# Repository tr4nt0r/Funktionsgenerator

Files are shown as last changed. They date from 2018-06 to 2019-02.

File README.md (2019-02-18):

# Funktionsgenerator
Funktionsgenerator basierend auf dem DDS AD9833 mit einem Atmega328PB (Arduino) als Mikrocontroller und einem 1,8" TFT Display

Function generator with AD9833 DDS, Atmega328PB Microcontroller and a 1.8" TFT Display

## Bill of Materials
### AD9833 & µController Board

| Qty | Value | Device | Package | Description | Vendor | Price |
| ---: | :--- | :--- | :--- | :--- | :--- | ---: |
| 1 | | KMR-1.8 SPI ST7735R | | 1.8" TFT Display |  [eBay](https://www.ebay.de/sch/i.html?_from=R40&_trksid=m570.l1313&_nkw=1%2C8%22+tft+spi+st7735r&_sacat=0) | 2,88€ |
| 1 | | SPDT | | Toggle switch for Front Panel Mount | [eBay](https://www.ebay.de/sch/i.html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) | 3,00€ |
| 1 |  | KY-040 | | Rotary Encoder mit Taster (Ausführung mit Gewinde am Schaft und Befestigungsmutter) |  [eBay](https://www.ebay.de/itm/Drehregler-Drehgeber-Rotary-Encoder-Arduino-KY-040-Potentiometer-Poti-Raspberry/252713917550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)| 4€ |
| 1 | 1,3k | Resistor | 0603 | | | 0,01€
| 1 | 620 | Resistor | 0603 |||0,01€|
| 8 | 100n | Capacitor | 0603 | | | 0,01€
| 4 | 10k | Resistor | 0603 ||| 0,01€|
| 1 | 10n | Capacitor| 0603||| 0,01€ |
| 1 |16Mhz | Crystal | SMD HC-49/U-S | 16.000MHz QCS HC49/U-S SMD Crystal 16MHz, 20ppm, 2-Pin HC-49/U-S SMD | [RS Components](https://de.rs-online.com/web/p/quarzmodule/8149535/)|0,25€|
| 1 | 1k |Potentiometer|| for Front Panel Mount | [RS Components](https://de.rs-online.com/web/p/products/8427030/)| 5,88€|
| 1 | 25k | Potentiometer || for Front Panel Mount| [RS Components](https://de.rs-online.com/web/p/products/8427059/)| 5,85€|
| 2 | 22p | Capacitor | 0603 | || 0,01€|
| 1 | 24.0Mhz | CFPS-72 | 7 x 5 mm SMD | | [RS Components](https://de.rs-online.com/web/p/products/8141581/)|1,25€|
|1 | 330n | Capacitor | 0603 | || 0,01€|
| 1 | | AD9833BRMZ | MSOP-10 | Programmable Waveform Generator | [Mouser](https://www.mouser.de/ProductDetail/Analog-Devices/AD9833BRMZ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) or [eBay](https://www.ebay.de/sch/i.html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)|7,79€|
| 1 | | ATMEGA328PB-AU | TQFP-32 | ATMEL - ATMEGA328PB-AU - MCU, 8BIT, ATMEGA, 20MHZ | [RS Components](https://de.rs-online.com/web/p/products/1468920/)|1,61€|
| 1 | 50Ohm | BNC Connector | | for Front Panel Mount | [RS Components](https://de.rs-online.com/web/p/products/5121174/)|2,15€|
| 1 | 10u | EEEFK1C100AR | Panasonic B | Panasonic 10uF 16 Vdc SMD Electrolytic Capacitor | [RS Components](https://de.rs-online.com/web/p/products/0565572/)|0,45€|
| 1 | 47u | Capacitor | Case D| Polarized Tantal Capacitor 10Vdc | [RS Components](https://de.rs-online.com/web/p/products/6993175/) | 0,36€|
| 2 | | LM318D | SO-08 | OpAmp | [RS Components](https://de.rs-online.com/web/p/products/6610524/) | 1,64€|
| 1 | | TLE4270-2D | TO-252 | LDO Voltage Regulator, 850mA, 5 V | [RS Components](https://de.rs-online.com/web/p/ldo-spannungsregler/1109087/) | 2,44€|

### Power Supply Board

| Qty | Value | Device | Package | Description | Vendor | Price |
| ---: | :--- | :--- | :--- | :--- | :--- | ---: |
|2 | 100n| Capacitor | 0603 | ||| 0,01€|
|1 | 2x12V 6VA | Transformer | | PCB Mount | [RS Components](https://de.rs-online.com/web/p/products/1213841/) | 5,75€|
|2 | 100u | EEEFT1C101AR | Panasonic C | Panasonic 100uF 16 Vdc SMD Electrolytic Capacitor | [RS Components](https://de.rs-online.com/web/p/aluminium-elektrolytkondensatoren/7472499/) | 0,35€|
|2 | 1000u/35V | Electrolyic Capacitor |E5-13| | [RS Components](https://de.rs-online.com/web/p/aluminium-elektrolytkondensatoren/7111337/) | 0,46€|
|1 | | MB6S| SOIC-4 | Bridge Rectifier | [RS Components](https://de.rs-online.com/web/p/products/6290322/)|0,35€|
| 1 |+12V| MC7812|DPAK| Positive Voltage Regulator| [RS Components](https://de.rs-online.com/web/p/products/6889250/)|0,70€|
|1|-12V| MC79M12|DPAK | Netgative Voltage Regulator|[RS Components](https://de.rs-online.com/web/p/products/6889326/)|0,65€|

#### Pin Connectors
You will need several pin headers and connectors , 2x2 Pin, 2x3 Pin, 1x 5 Pin. You could use any connector with a pitch of 0,1"/2,54mm either regular pinheaders or [Molex KK 254 Connectors](https://de.rs-online.com/web/c/steckverbinder/leiterplattensteckverbinder/leiterplatten-header/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,4293240458,4294519411,4294519436,4294516238,4294878123).

### Images

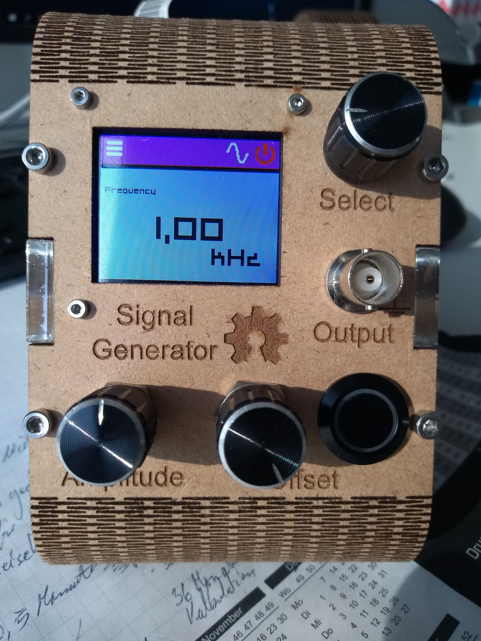
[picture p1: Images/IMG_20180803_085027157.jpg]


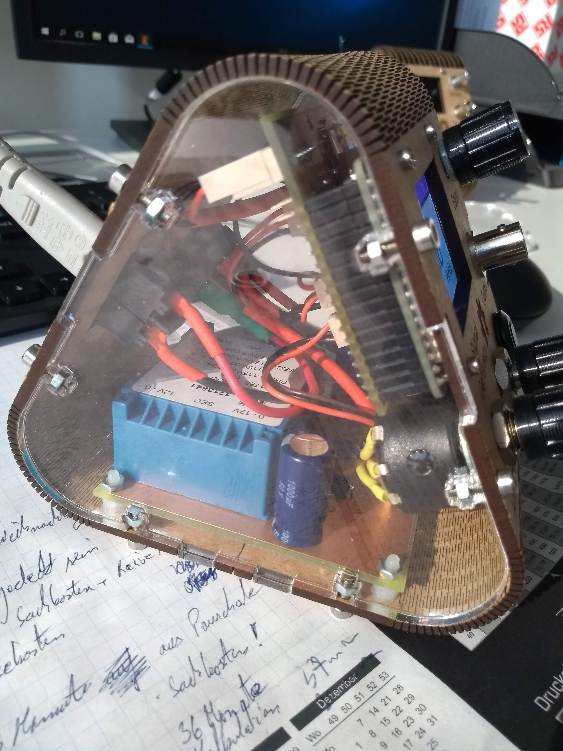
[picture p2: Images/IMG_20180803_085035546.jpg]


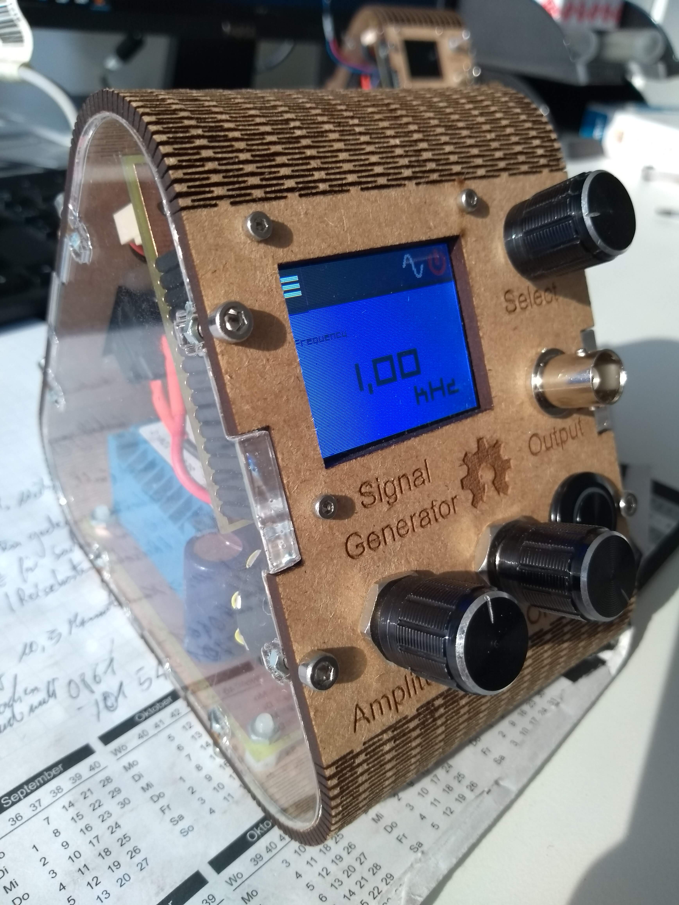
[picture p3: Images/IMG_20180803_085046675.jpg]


This work is based on this [howto](https://www.allaboutcircuits.com/projects/how-to-DIY-waveform-generator-analog-devices-ad9833-ATmega328p/) from allaboutcircuits.com

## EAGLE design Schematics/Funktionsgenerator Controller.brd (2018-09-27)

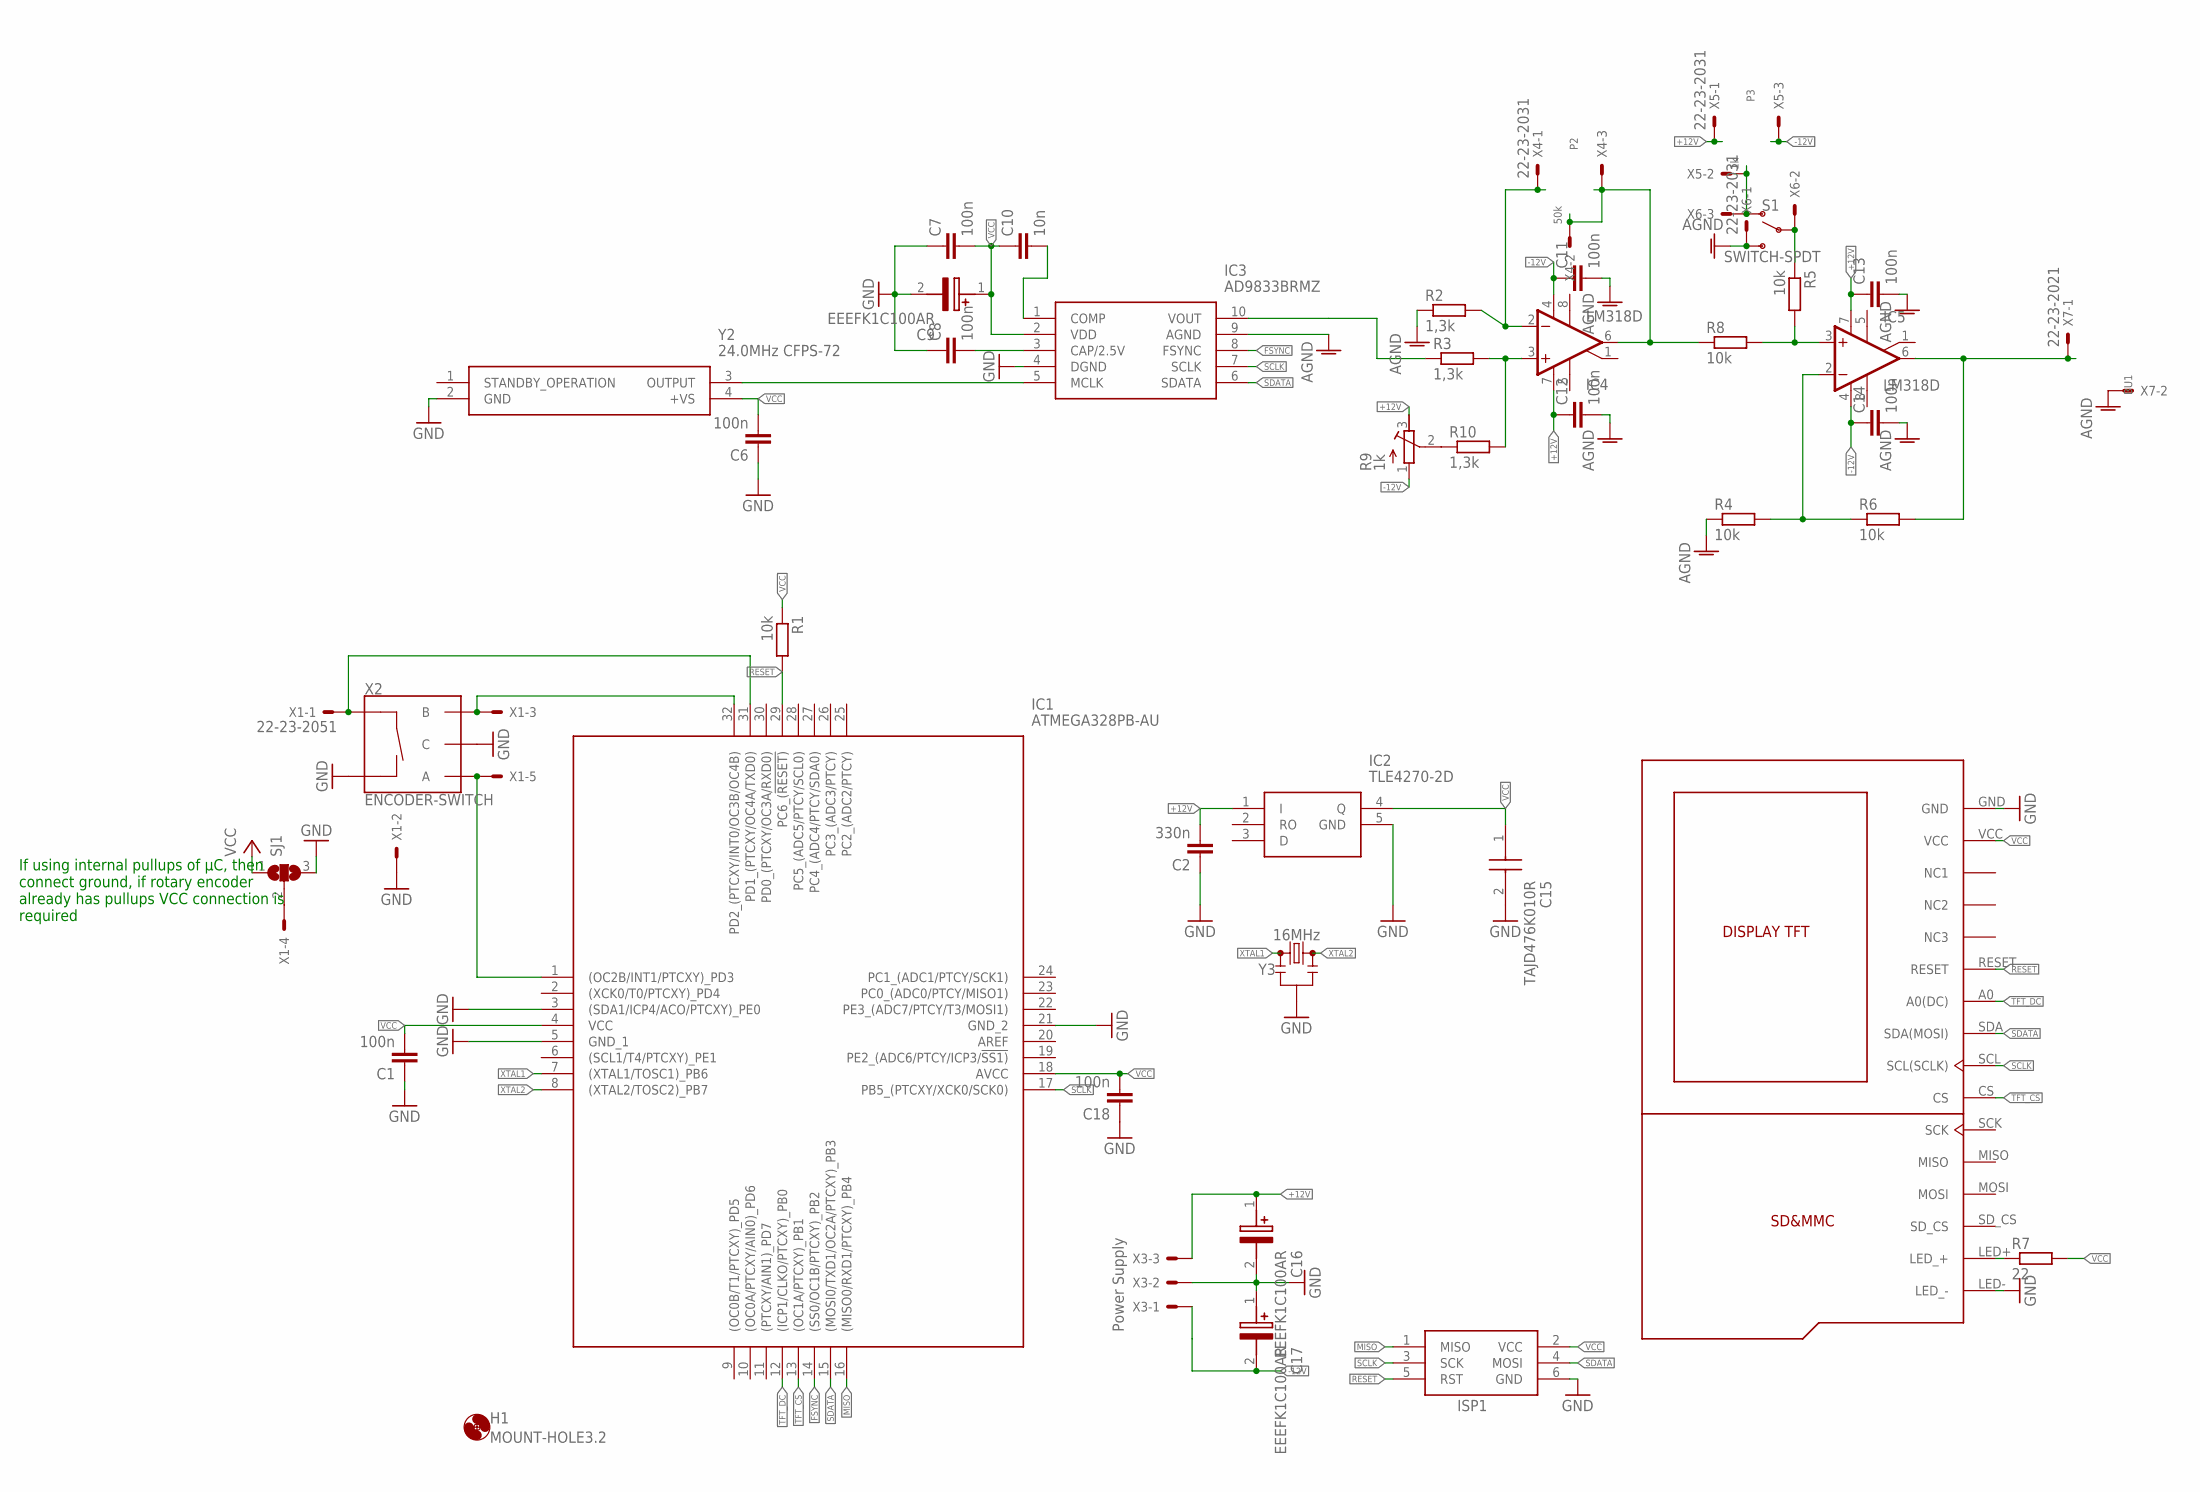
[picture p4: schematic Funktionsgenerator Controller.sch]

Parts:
C1, C6, C7, C8, C11, C12, C13, C14, C18: 100n; C0603
C2: 330n; C0603
C9, C16, C17: EEEFK1C100AR; FKV(B)
C10: 10n; C0603
C15: TAJD476K010R; CAPPM7344X310N
H1: MOUNT-HOLE3.2; 3,2
IC1: ATMEGA328PB-AU; QFP80P900X900X120-32N
IC2: TLE4270-2D; PG-TO252-5-11
IC3: AD9833BRMZ; SOP50P490X110-10N
IC4, IC5: LM318D; SO08
ISP1: AVRISP-6; AVRISP
P1: DISPLAY_TFT_1,8; DISPLAY_TFT_1,8-KMR
R1, R4, R5, R6, R8: 10k; R0603
R2, R3, R10: 1,3k; R0603
R7: 22; R0603
R9: 1k; EVM3ESX50B
SJ1: SJ2W; SJ_2
X1: 22-23-2051
X3: Power Supply; 22-23-2031
X4, X5, X6: 22-23-2031
X7: 22-23-2021
Y2: 24.0MHz CFPS-72; CFPS-72
Y3: 16MHz; RESONATOR-SMD-3.2X1.3

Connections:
+12V: C2.2, C12.1, C13.1, C16.1 (+), IC2.1 (I), IC4.7 (V+), IC5.7 (V+), R9.3 (E), X3.3, X5.1
-12V: C11.1, C14.1, C17.2 (-), IC4.4 (V-), IC5.4 (V-), R9.1 (A), X3.1, X5.3
AGND: C11.2, C12.2, C13.2, C14.2, IC3.9 (AGND), R2.1, R4.1, X6.1, X7.2
FSYNC: IC1.14 ((SS0/OC1B/PTCXY)_PB2), IC3.8 (FSYNC)
GND: C1.1, C2.1, C6.1, C7.1, C8.1, C9.2 (-), C15.2 (-), C16.2 (-), C17.1 (+), C18.1, IC1.3 ((SDA1/ICP4/ACO/PTCXY)_PE0), IC1.5 (GND_1), IC1.21 (GND_2), IC2.5 (GND), IC3.4 (DGND), ISP1.6 (GND), P1.GND, P1.LED- (LED_-), SJ1.3, X1.2, X3.2, Y2.2 (GND), Y3.2
MISO: IC1.16 ((MISO0/RXD1/PTCXY)_PB4), ISP1.1 (MISO)
unnamed: IC3.5 (MCLK), Y2.3 (OUTPUT)
unnamed: C8.2, IC3.3 (CAP/2.5V)
unnamed: IC4.3 (+IN), R3.2, R10.2
unnamed: C10.2, IC3.1 (COMP)
unnamed: IC3.10 (VOUT), R3.1
unnamed: IC4.2 (-IN), R2.2, X4.1
unnamed: R5.1, X6.2
unnamed: X5.2, X6.3
unnamed: IC4.6 (OUT), R8.1, X4.2, X4.3
unnamed: IC5.6 (OUT), R6.2, X7.1
unnamed: IC5.2 (-IN), R4.2, R6.1
unnamed: SJ1.2, X1.4
unnamed: IC5.3 (+IN), R5.2, R8.2
unnamed: R9.2 (S), R10.1
unnamed: P1.LED+ (LED_+), R7.1
RESET: IC1.29 (PC6_(!RESET)), ISP1.5 (RST), P1.RESET, R1.2
ROT_A: IC1.1 ((OC2B/INT1/PTCXY)_PD3), X1.5
ROT_B: IC1.32 (PD2_(PTCXY/INT0/OC3B/OC4B)), X1.3
ROT_BTN: IC1.31 (PD1_(PTCXY/OC4A/TXD0)), X1.1
SCLK: IC1.17 (PB5_(PTCXY/XCK0/SCK0)), IC3.7 (SCLK), ISP1.3 (SCK), P1.SCL (SCL(SCLK))
SDATA: IC1.15 ((MOSI0/TXD1/OC2A/PTCXY)_PB3), IC3.6 (SDATA), ISP1.4 (MOSI), P1.SDA (SDA(MOSI))
TFT_CS: IC1.13 ((OC1A/PTCXY)_PB1), P1.CS
TFT_DC: IC1.12 ((ICP1/CLKO/PTCXY)_PB0), P1.A0 (A0(DC))
VCC: C1.2, C6.2, C7.2, C9.1 (+), C10.1, C15.1 (+), C18.2, IC1.4 (VCC), IC1.18 (AVCC), IC2.4 (Q), IC3.2 (VDD), ISP1.2 (VCC), P1.VCC, R1.1, R7.2, SJ1.1, Y2.4 (+VS)
XTAL1: IC1.7 ((XTAL1/TOSC1)_PB6), Y3.1
XTAL2: IC1.8 ((XTAL2/TOSC2)_PB7), Y3.3

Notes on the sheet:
If using internal pullups of µC, then connect ground, if rotary encoder already has pullups VCC connection is required

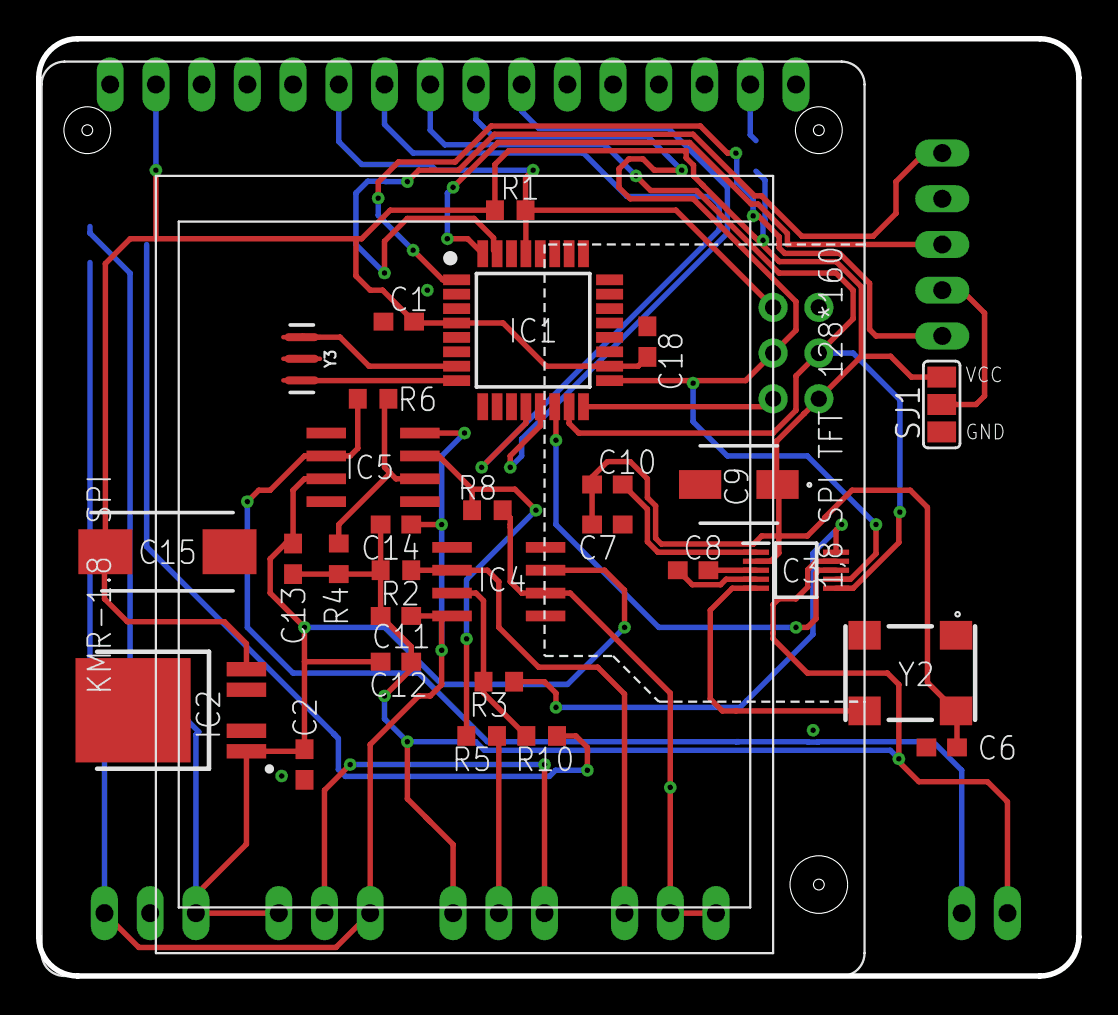
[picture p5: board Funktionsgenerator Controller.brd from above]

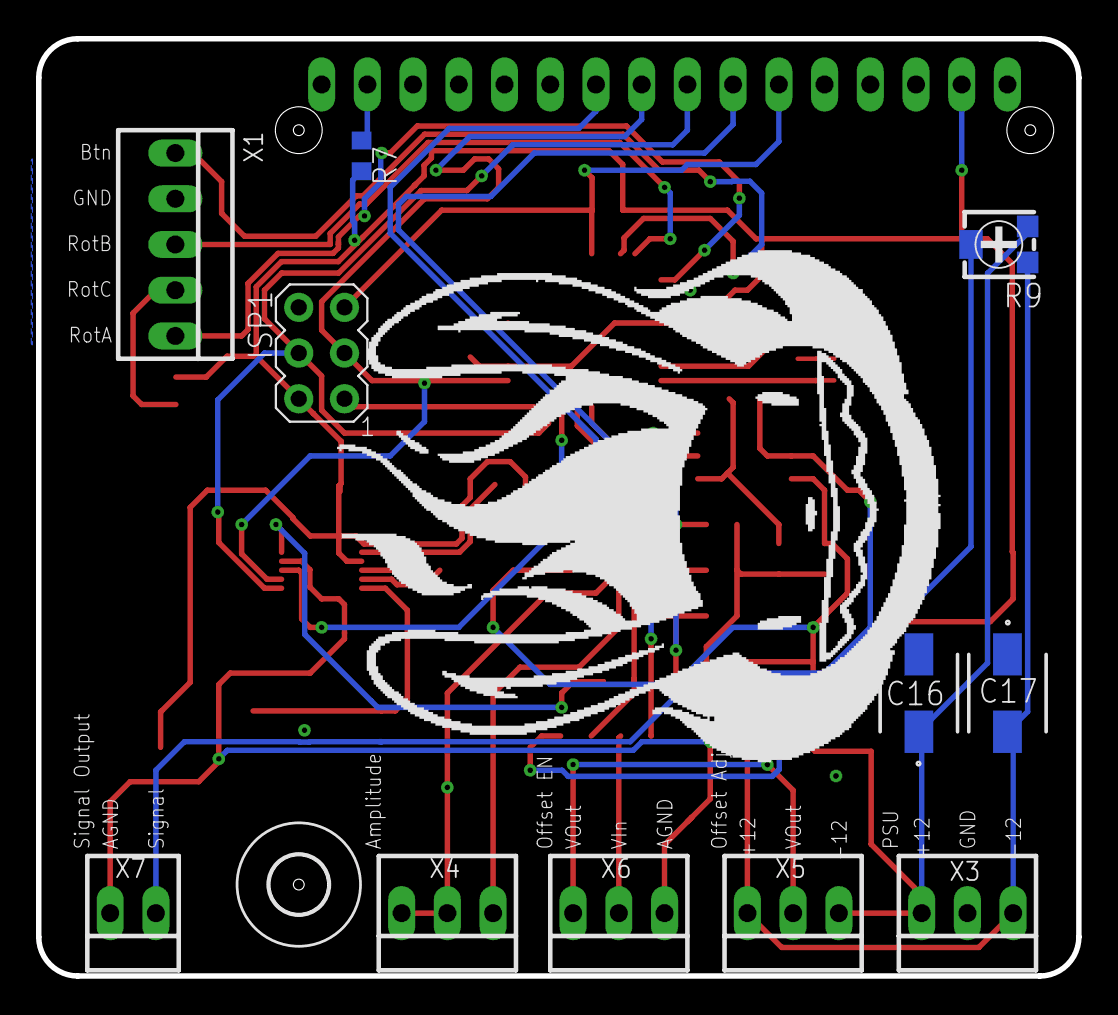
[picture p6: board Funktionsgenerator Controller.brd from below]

Board: 2 copper layers, 57.8 x 52.1 mm, 42 parts (12 on the bottom side), 32 nets.

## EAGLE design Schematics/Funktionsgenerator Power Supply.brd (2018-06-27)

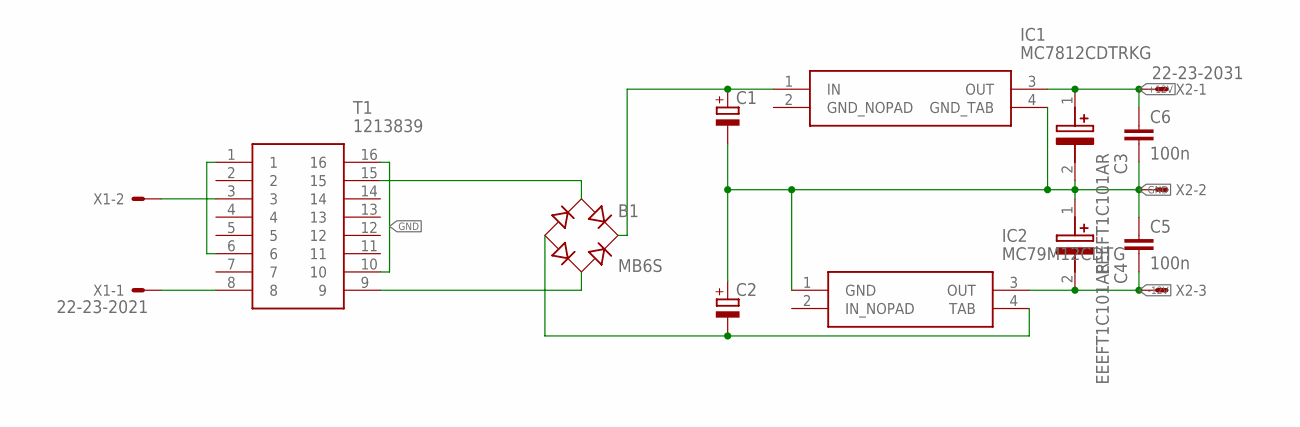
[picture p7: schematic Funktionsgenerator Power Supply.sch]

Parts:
B1: MB6S; SOIC-4
C1, C2: CPOL-EUE5-13; E5-13
C3, C4: EEEFT1C101AR; HBV(C)
C5, C6: 100n; C0603
IC1: MC7812CDTRKG; TO229P990X238-4N
IC2: MC79M12CDTG; TO229P990X238-4N
T1: 1213839; DIPS3500W80P500L4400H2300Q16N
X1: 22-23-2021
X2: 22-23-2031

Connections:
+12V: C3.1 (+), C6.1, IC1.3 (OUT), X2.1
-12V: C4.2 (-), C5.2, IC2.3 (OUT), X2.3
GND: C1.-, C2.+, C3.2 (-), C4.1 (+), C5.1, C6.2, IC1.4 (GND_TAB), IC2.1 (GND), T1.10, T1.16, X2.2
GND_NOPAD: IC1.2 (GND_NOPAD)
unnamed: T1.1, T1.6
unnamed: T1.3, X1.2
unnamed: T1.8, X1.1
unnamed: B1.~1 (AC1), T1.15
unnamed: B1.~2 (AC2), T1.9
unnamed: B1.-, C2.-, IC2.4 (TAB)
unnamed: B1.+, C1.+, IC1.1 (IN)

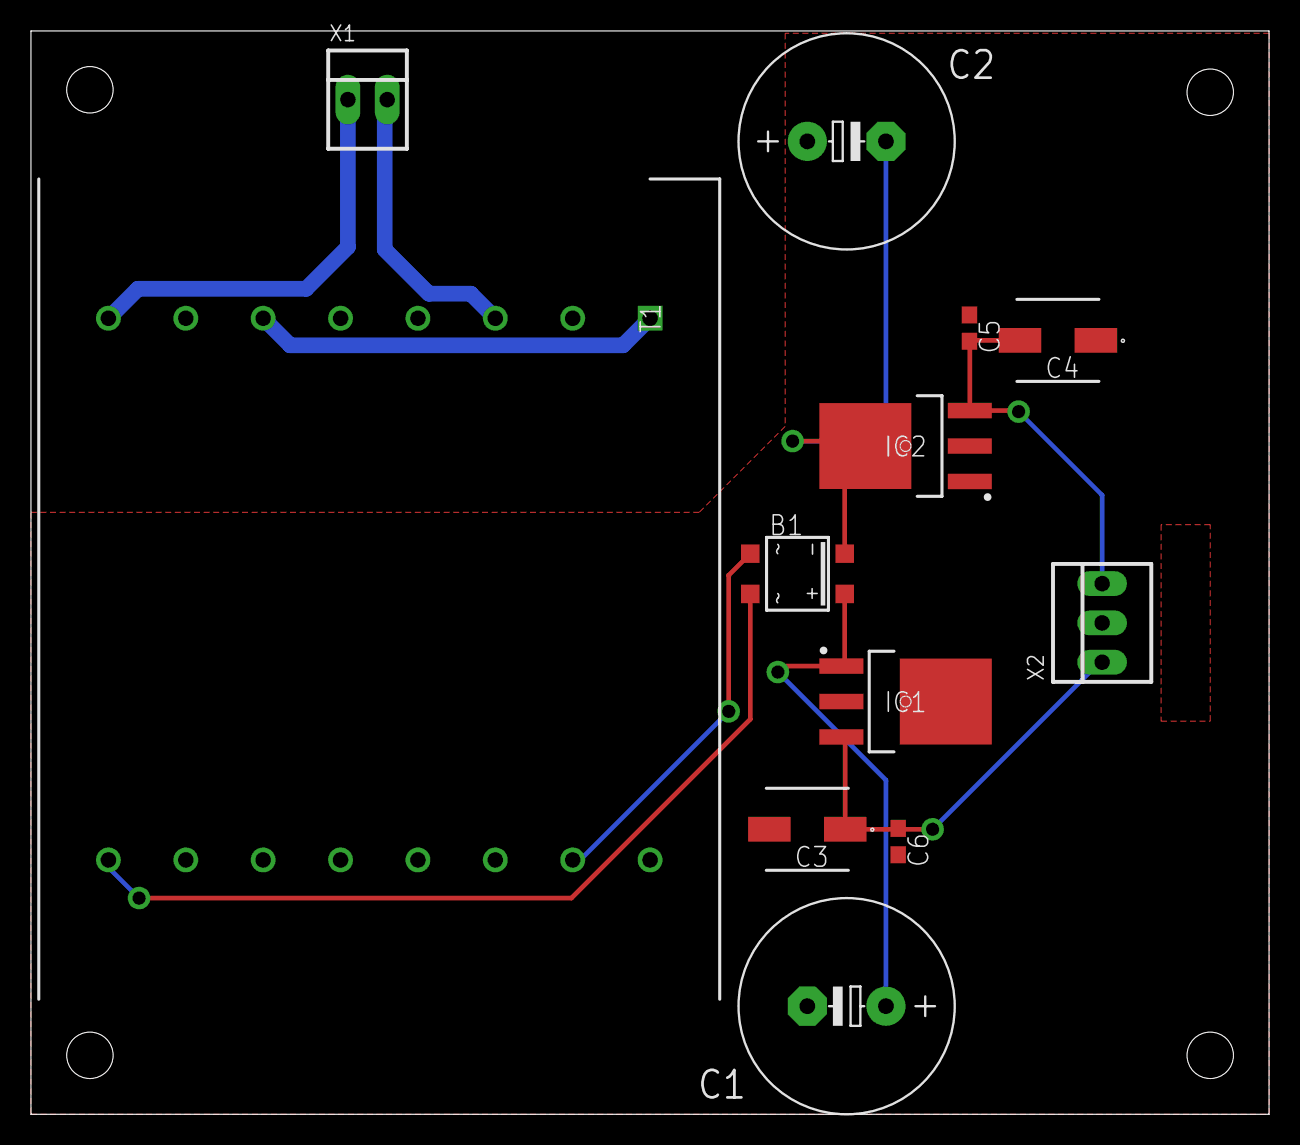
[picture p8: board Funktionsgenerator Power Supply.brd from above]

Board: 2 copper layers, 80.0 x 70.0 mm, 12 parts (0 on the bottom side), 10 nets.

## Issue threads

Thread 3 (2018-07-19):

Replace Pots and Switch with Digital Pots

tr4nt0r, 2018-07-19:
If Pots are replaced with Digital Pots Amplitude and Offset could be set via Software.

Closed 2024-04-27.

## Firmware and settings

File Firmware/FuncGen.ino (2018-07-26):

#include <gfxfont.h>
#include <Adafruit_GFX.h>
#include <Adafruit_ST77xx.h>
#include <Adafruit_ST7735.h>
#include "definitions.h"
#include "AD9833.h"
#include <Fonts\Org_01.h>
#include <TimerOne.h>
#include <ClickEncoder.h>




AD9833 sigGen(AD9833_FsyncPin, AD9833_ClkFreq); // Initialise our AD9833 with FSYNC pin = 10 and a master clock frequency of 24MHz
ClickEncoder encoder(rotaryEncoderPinA, rotaryEncoderPinB, rotaryEncoderPinBtn, 4);
Adafruit_ST7735 tft = Adafruit_ST7735(TFT_CS, TFT_DC, -1);

//for some reason, compiler sometimes needs forward declaration ¯\_(ツ)_/¯ 
void drawMenuBar();
void drawMainScreen();
void drawMainScreenWaveform(bool drawPartial = false);
void drawMainScreenFrequency(bool drawPartial = false);
Menu::Menu_e getNextMenuItem(Direction::dir direction);
void changeFrequencyDigit(Direction::dir dir, uint8_t digitPos);
void changeFrequency(Direction::dir dir);
void callButtonEvent(ClickEncoder::Button button);


void setup() {
	initTFT();
	displayBootUpMsg(); //display Bootscreen for 2s
	drawMenuBar();
	drawMainScreen(); //renders Mainscreen Boxes


					  // Initialise the AD9833 with 1KHz sine output, no phase shift for both
					  // registers and remain on the FREQ0 register
	sigGen.reset(1);
	sigGen.setFreq(frequency);
	sigGen.setPhase(phase);
	sigGen.setFPRegister(1);
	sigGen.setFreq(frequency);
	sigGen.setPhase(phase);
	sigGen.setFPRegister(0);
	sigGen.mode(selectedWaveform);
	sigGen.reset(0);

	Timer1.initialize(1000);
	Timer1.attachInterrupt(ISRcallback);

	encoder.setAccelerationEnabled(true);
}

void onRotaryEncoderTurnEvent() {

	rotaryEncoderPos += encoder.getValue();
	Direction::dir dir = Direction::NONE;

	int8_t rotaryEncoderMovement = rotaryEncoderPos - rotaryEncoderLastPos;
	if (rotaryEncoderMovement != 0) {
		dir = (rotaryEncoderMovement > 0) ? Direction::CW : Direction::CCW;
		rotaryEncoderLastPos = rotaryEncoderPos;
		isAccelerated = (abs(rotaryEncoderMovement) > 1) ? true : false;
 	}
	else {
		dir = Direction::NONE;
	}

	//navigate menu if no Menu item currently selected
	if (dir != Direction::NONE && menuSelected != Menu::NullItem && menuSelected != menuActive) {
		if (menuSelected != getNextMenuItem(dir)) {
			menuSelected = getNextMenuItem(dir);
			drawMenuBar();
		}
	}
	//rotary encoder actions if a menu item is active
	else if (dir != Direction::NONE && menuSelected == menuActive) {
		switch (menuActive)
		{
		case Menu::NullItem:
			changeFrequency(dir);
			drawMainScreenFrequency(true);
			sigGen.setFreq(frequency);
			break;
		case Menu::FreqSet:
			changeFrequencyDigit(dir, digitPos);
			break;
		case Menu::Mode:
			if (dir == Direction::CW && selectedWaveform < 2) {
				selectedWaveform++;
				drawMainScreenWaveform(true);
				sigGen.mode(selectedWaveform);
			} else if (dir == Direction::CCW && selectedWaveform > 0) {
				selectedWaveform--;
				drawMainScreenWaveform(true);
				sigGen.mode(selectedWaveform);
			}
			break;
		//case Menu::Power:
		//	break;
		//case Menu::Phase:
		//	break;
		//case Menu::Settings:
		//	break;
		//case Menu::lastItem:
		//	break;
		//default:
		//	break;
		}
	}
}

//change digit or unit in frequency set menu
void changeFrequencyDigit(Direction::dir dir, uint8_t digitPos) {
	int8_t rnew;

	if (digitPos == numDigits) {
		if (dir == Direction::CW)
			newFrequencyExp = (newFrequencyExp == 6) ? 6 : newFrequencyExp + 3;
		else
			newFrequencyExp = (newFrequencyExp == 0) ? 0 : newFrequencyExp - 3;
	} else {
		if (dir == Direction::CW)
			newFrequency[digitPos] = (newFrequency[digitPos] == 9) ? 0 : newFrequency[digitPos] + 1;
		else
			newFrequency[digitPos] = (newFrequency[digitPos] == 0) ? 9 : newFrequency[digitPos] - 1;
	}	

	drawMainScreenFreqSet();
}

//change frequency in MainScreen
void changeFrequency(Direction::dir dir) {
	uint32_t step;

	if (frequency > 1000000) { //MHz
		step = (isAccelerated) ? 100000 : 10000;
		if (dir == Direction::CCW && frequency - step < 1000000)
			step = abs(frequency - 1000000);
		if (dir == Direction::CW && frequency + step > maxFrequency)
			step = maxFrequency - frequency;
	} else if (frequency > 1000) { //kHz
		step = (isAccelerated) ? 1000 : 10;
		if (dir == Direction::CCW && frequency - step < 1000)
			step = abs(frequency - 1000);
	} else {
		step = (isAccelerated) ? 100 : 1;
		if (dir == Direction::CCW && frequency <= step)
			step = abs(frequency - 1);
	}
	frequency += (dir == Direction::CW) ? step : step*-1;
}

//Interrupt Service Routine 
void ISRcallback() {
	encoder.service();
}



Menu::Menu_e getNextMenuItem(Direction::dir direction) {
	uint8_t next = (int)menuSelected;
	if (direction == Direction::CW && next < Menu::lastItem - 1) {
		next++;
	}
	else if (direction == Direction::CCW && next > Menu::NullItem + 1) {
		next--;
	}
	return (Menu::Menu_e)next;
}

void callButtonEvent(ClickEncoder::Button button) {
	switch (button) {
	case ClickEncoder::Open:
	default:
		//	  
		break;
	case ClickEncoder::Clicked:
		onClick();
		break;
	case ClickEncoder::DoubleClicked:
		onDblClick();
		break;
	case ClickEncoder::Held:
		onButtonHold();
		break;
	case ClickEncoder::Released:
		onButtonUp();
		break;
	}
}

void onDblClick() {
	switch (menuSelected) {
	case Menu::NullItem: //No Menu Item selected
		if (menuActive == Menu::NullItem) {
			menuSelected = Menu::FreqSet;
			drawMenuBar();
		}
		break;
	default:			
			menuSelected = Menu::NullItem;
			menuActive = Menu::NullItem;
			digitPos = 0;
			drawMenuBar();
			drawMainScreen();
		break;
	}
}

void onButtonHold() {	
	switch (menuSelected) {
	case Menu::NullItem: //No Menu Item selected
		if (menuActive == Menu::NullItem && !buttonIsHeld) {
			togglePowerState();
			drawMenuBar();
		}
		break;
	default:
		if (!buttonIsHeld) { //close menu
			//menuSelected = NullItem;
			//menuActive = NullItem;
			//drawMenuBar();
			//drawMainScreen();
		}
		break;
	}
	buttonIsHeld = true;  //prevents repeated button held events
};

void togglePowerState() {
	currentPowerState ^= true;
	// Turn DAC and clock ON/OFF
	(currentPowerState) ? sigGen.sleep(3) : sigGen.sleep(0);
}

void onClick() {

	if (menuSelected != Menu::NullItem && menuSelected != menuActive) {
		menuActive = menuSelected;
		drawMenuBar();
		drawMainScreen();
	} else if (menuSelected == menuActive) {

		//drawMainScreen();
		switch (menuActive) {
		case Menu::NullItem:
			break;
		case Menu::FreqSet:

			//with each click cursor switches to next digit			

			if (digitPos < numDigits) {
				digitPos++;
				drawMainScreenFreqSet();

			} else {
				digitPos = 0;

				for (uint8_t i = 0; i < numDigits; i++) {

				}

				frequency = getFrequencyFromDigits();
				menuActive = Menu::NullItem;
				drawMenuBar();
				drawMainScreenFrequency();
				sigGen.setFreq(frequency);
			}

			break;
		//case Mode:
		//	break;
		//case Power:
		//	break;
		//case Phase:
		//	break;
		//case Sweep:
		//	break;
		//case Settings:
		//	break;
		//case Help:
		//	break;
		//case lastItem:
		//	break;
		default:
			menuActive = Menu::NullItem;
			drawMenuBar();
			break;
		}

	}

}

uint32_t getFrequencyFromDigits() {
	uint32_t f = 0;

	for (uint8_t i = 0; i < numDigits; i++) {
		if (newFrequencyExp != 0 || i <= 2)
			f += newFrequency[i] * pow(10, newFrequencyExp - 2 + numDigits - i - 1);		
	}
	if (f > maxFrequency)
		return maxFrequency;
	if (f == 0)
		return 1;
	return f;
}
void onButtonUp() {
	//reset button hold status
	if (buttonIsHeld == true) {
		buttonIsHeld = false;
	}
};

//
//void encChange() {
//  // Depending in which menu state you are
//  // the encoder will either change the value of a setting:
//  //-+ frequency, change between FREQ0 and FREQ1 register (or -+ phase), On/Off, mode
//  // or it will change the cursor position
//
//
//	rotaryEncoderDir dir = DIR_NONE;
//  // Direction clockwise
//  if (dir == DIR_CW) {
//    switch (menuSelected) {
//      case 1: {
//          if (cursorPos == 3)
//            cursorPos = 0;
//          else
//            cursorPos++;
//        } break;
//
//      case 2: {
//          // Here we initialise two variables.
//          // newFrequency is the value of the frequency after we increment it
//          // dispDigit is the digit that we are currently modifing, and we obtain it
//          // by a neat little trick, using operator % in conjunction with division
//          // We then compare these variables with the maximum value for our
//          // frequency, if all is good, make the change
//          unsigned long newFrequency = frequency + pow(10, digitPos);
//          unsigned char dispDigit =
//            frequency % (unsigned long) pow(10, digitPos + 1) / pow(10, digitPos);
//          if (newFrequency <= maxFrequency && dispDigit < 9) {
//            frequency += pow(10, digitPos);
//            updateDisplay = true;
//          }
//
//          if (freqRegister == 0) {
//            frequency0 = frequency;
//          } else if (freqRegister == 1) {
//            frequency1 = frequency;
//          }
//
//        } break;
//
//      case 4: {
//          // if usePhase has been defined, changes in the encoder will vary the phase
//          // value (upto 4096)
//          // A better implementation would be to use increment of pi/4 or submultiples of
//          // pi where 2pi = 4096
//#ifdef usePhase
//          unsigned long newPhase = phase + pow(10, digitPos);
//          unsigned char dispDigit =
//            phase % pow(10, digitPos + 1) / pow(10, digitPos);
//          if (newPhase < maxPhase && dispDigit < 9) {
//            phase += pow(10, digitPos);
//            updateDisplay = true;
//          }
//#endif
//        } break;
//
//      case 5: {
//          if (selectedWaveform == 2)
//            selectedWaveform = 0;
//          else
//            selectedWaveform++;
//          updateDisplay = true;
//        } break;
//    }
//  }
//  // Direction counter clockwise
//  else if (dir == DIR_CCW) {
//    switch (menuSelected) {
//      case 1: {
//          if (cursorPos == 0)
//            cursorPos = 3;
//          else
//            cursorPos--;
//        } break;
//
//      case 2: {
//          unsigned long newFrequency = frequency + pow(10, digitPos);
//          unsigned char dispDigit = frequency % (unsigned long) pow(10, digitPos + 1) / pow(10, digitPos);
//
//          if (newFrequency > 0 && dispDigit > 0) {
//            frequency -= pow(10, digitPos);
//            updateDisplay = true;
//          }
//
//          if (freqRegister == 0) {
//            frequency0 = frequency;
//          } else if (freqRegister == 1) {
//            frequency1 = frequency;
//          }
//        } break;
//
//      case 4: {
//          // if usePhase has been defined, changes in the encoder will vary the phase
//          // value (upto 4096)
//          // A better implementation would be to use increment of pi/4 or submultiples of
//          // pi where 2pi = 4096
//#ifdef usePhase
//          unsigned long newPhase = phase + pow(10, digitPos);
//          unsigned char dispDigit =
//            phase % pow(10, digitPos + 1) / pow(10, digitPos);
//          if (newPhase > 0 && dispDigit > 0) {
//            phase -= pow(10, digitPos);
//            updateDisplay = true;
//          }
//#endif
//        } break;
//
//      case 5: {
//          if (selectedWaveform == 0)
//            selectedWaveform = 2;
//          else
//            selectedWaveform--;
//          updateDisplay = true;
//        } break;
//    }
//  }
//}


// Function to display the current frequency in the top left corner
void displayFrequency() {
  unsigned long frequencyToDisplay = frequency;
  
  tft.setCursor(4, 10);
  tft.setTextColor(GREEN);
  tft.setTextSize(1);
  int16_t x1, y1;
  uint16_t w, h;
  tft.getTextBounds(F("F="), 4, 10, &x1, &y1, &w, &h);
  tft.fillRect(x1, y1, tft.width() - 8, h, BLACK);
  tft.print(F("F="));

  if (frequency >= 1000000) {
	  tft.print(frequency / 1000000.0, 4);
	  tft.println(F(" GHz"));
  } else if (frequency >= 1000) {
	  tft.print(frequency / 1000.0, 3);
	  tft.println(F(" MHz"));
  } else {
	  tft.print(frequency);
	  tft.println(F(" Hz"));
  }
 
}
// Function to display power state (ON/OFF) in the top right corner
//void displayPower() {
//	tft.setCursor(4, 30);
//	tft.setTextColor(GREEN);
//	tft.setTextSize(1);
//	//tft.print(powerState[currentPowerState]);
//}
//// Function to display the mode in the bottom right corner
//void displayMode() {
//	tft.setTextColor(GREEN);
//	tft.setTextSize(1);
//	tft.setCursor(4, 60);
//	tft.print(waveformLabel[selectedWaveform]);
//}
// Function to display the mode in the bottom left corner
// Only used if you enable PHASE setting instead of FREQ register
//void displayPhase() {
//  unsigned int phaseToDisplay = phase;
//  //lcd.setCursor(0, 1);
//  //lcd.write(0);
//  //lcd.print("=");
//  for (int i = 3; i >= 0; i--) {
//    unsigned int dispDigit = phaseToDisplay / pow(10, i);
//    //lcd.print(dispDigit);
//    phaseToDisplay -= dispDigit * pow(10, i);
//  }
//}
// Function to display the FREQ register (either 0 or 1) in the bottom left
// corner
//void displayFreqRegister() {
//	tft.setCursor(4, 90);
//	tft.setTextSize(1);
//	tft.setTextColor(GREEN);	
//	tft.print("Preset ");
//	tft.print(freqRegister);
//}

//void displayChange() {
//	return;
//	// Update display if needed
//	if (updateDisplay == true) {
//		displayFrequency();
//#ifdef usePhase
//		displayPhase();
//#endif
//		displayPower();
//#ifndef usePhase
//		displayFreqRegister();
//#endif
//		displayMode();
//		updateDisplay = false;
//	}
//}

void displayDebugMsg(uint32_t msg) { displayDebugMsg((String)msg); }
void displayDebugMsg(String msg) {
#ifdef DEBUG
	tft.setTextSize(1);	
	tft.setCursor(4, 120);
	int16_t x1, y1;
	uint16_t w, h;
	tft.getTextBounds((char*)msg.c_str(), 4, 120, &x1, &y1, &w, &h);
	tft.fillRect(x1, y1, tft.width(), h, PALEVIOLET);
	tft.print(msg);
#endif // DEBUG
}

void drawMainScreen() {	
	tft.fillRect(0, tft.height() / 5 + 4, tft.width(), tft.height() * 4 / 5, PALEVIOLET);	
	switch (menuActive) {
	case Menu::NullItem:
		if (menuSelected == Menu::NullItem)
			drawMainScreenFrequency();
		break;
	case Menu::FreqSet:
		//when entering FreqSet Menu initialize digits with actual frequency
		if (digitPos == 0) {
			numDigits = 5;
			newFrequencyExp = 0;
			if (frequency >= 1000000)
				newFrequencyExp = 6;
			else if (frequency >= 1000)
				newFrequencyExp = 3;

			for (uint8_t i = 0; i < numDigits; i++) {
				if (newFrequencyExp == 0 && i > 2)
					newFrequency[i] = 0;
				else {
					newFrequency[i] = frequency / pow(10, numDigits - 1 - i + newFrequencyExp - 2) % 10;
				}
			}
		}

		drawMainScreenFreqSet();
		break;
	case Menu::Mode:
		drawMainScreenWaveform();
		break;
	case Menu::Power:
		break;
	case Menu::Phase:
		break;
	case Menu::Settings:
		break;
	case Menu::lastItem:
		break;
	default:
		break;
	}
}

void drawMainScreenWaveform(bool drawPartial) {
	//don't draw if partial redraw requested, reduces flickering
	if (drawPartial == false) {
		tft.setTextColor(BLACK);
		tft.setTextSize(1);
		tft.setCursor(4, 50);
		tft.print(F("Select Waveform:"));

		tft.drawBitmap(16, 59, sineWave32, 32, 32, PALEVIOLET, WHITE);
		tft.drawBitmap(64, 59, triangleWave32, 32, 32, PALEVIOLET, WHITE);
		tft.drawBitmap(112, 59, squareWave32, 32, 32, PALEVIOLET, WHITE);
	}
	tft.setTextColor(BLACK);
	tft.fillRect(0, 95, tft.width(), 15, PALEVIOLET);
	printAlignCenter(waveformLabel[selectedWaveform], 2, tft.width() / 2, 100);
	//highlight active waveform by drawing a rectangle bihind the icon
	tft.drawRect(14, 57, 36, 36, (selectedWaveform == 0) ? HOTMAGENTA : PALEVIOLET);
	tft.drawRect(62, 57, 36, 36, (selectedWaveform == 1) ? HOTMAGENTA : PALEVIOLET);
	tft.drawRect(110, 57, 36, 36, (selectedWaveform == 2) ? HOTMAGENTA : PALEVIOLET);

}

void drawMainScreenFrequency(bool drawPartial) {
	uint8_t exp = 0, dec = 0;	
	String PROGMEM unit;
	bool isTrailZero = true;

	tft.setTextColor(BLACK);
	if (!drawPartial) {
		tft.fillRect(0, 45, tft.width(), 10, PALEVIOLET);
		tft.setCursor(4, 50);
		tft.setTextSize(1);
		tft.print(F("Frequency"));
	}

	if (frequency >= 1000000) {
		unit = F("MHz");
		exp = 6;
		numDigits = 5;  //show 5 digits, 2 digits as decimal
		dec = 2;
	} else if (frequency >= 1000) {
		unit = F("kHz");
		exp = 3;
		numDigits = 5;
		dec = 2;
	} else {
		unit = F("Hz");
		numDigits = 3;	
	}
	tft.fillRect(0, 65, tft.width(), 30, PALEVIOLET);
	String output;

	for (uint8_t i = numDigits; i > 0; i--) {
		uint32_t r = frequency / pow(10, (i - 1) + exp - dec) % 10;
		if (!isTrailZero || r != 0) { //suppress trailing zeros
			if (i == dec)
				output += F(",");
			output += (String)r;
			isTrailZero = false;
		}
	}
	printAlignCenter(output, 4, tft.width() / 2, 75);
	tft.setTextSize(3);
	tft.setCursor(100, 110);
	tft.fillRect(100, 95, 100, 20, PALEVIOLET);
	tft.print(unit);
}
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
void loop() {
	// Check to see if the button has been pressed  
	callButtonEvent(encoder.getButton());
	//checks if rotary encoder has been turned and                                                                                                                                                                   
	onRotaryEncoderTurnEvent();


	//  switch (menuState) {
	//    // Default state
	//    case 0: {
	//        
	//          //button = 1;
	//          //lcd.setCursor(0, 0);
	//          //lcd.blink();
	//          menuState = 1;
	//          cursorPos = 0;
	//   
	//      } break;
	//    // Settings mode
	//    case 1: {
	//        if (button == 0) {
	//          //button = 1;
	//          // If the setting in Power just toggle between on and off
	//          if (cursorPos == 1) {
	//            currentPowerState = abs(1 - currentPowerState);
	//            updateDisplay = true;
	//            menuState = 0;
	//            if (currentPowerState == 1)
	//              sigGen.sleep(3); // Both DAC and clock turned OFF
	//            else
	//              sigGen.sleep(0); // DAC and clock are turned ON
	//          }
	//          // If usePhase has not been set
	//#ifndef usePhase
	//          else if (cursorPos == 2) {
	//            updateDisplay = true;
	//            menuState = 0; // return to "main menu"
	//            if (freqRegister == 0) {
	//              freqRegister = 1;
	//              sigGen.setFPRegister(1);
	//              frequency = frequency1;
	//            } else {
	//              freqRegister = 0;
	//              sigGen.setFPRegister(0);
	//              frequency = frequency0;
	//            }
	//          }
	//#endif
	//          // Otherwise just set a new state
	//          else
	//            menuState = cursorPos + 2;
	//        }
	//        // Move the cursor position in case it changed
	//        if (lastCursorPos != cursorPos) {
	//          unsigned char realPosR = 0;
	//          unsigned char realPosC;
	//          if (settingsPos[cursorPos] < 16)
	//            realPosC = settingsPos[cursorPos];
	//          else {
	//            realPosC = settingsPos[cursorPos] - 16;
	//            realPosR = 1;
	//          }
	//          //lcd.setCursor(realPosC, realPosR);
	//          lastCursorPos = cursorPos;
	//        }
	//      } break;
	//    // Frequency setting
	//    case 2: {
	//        // Each button press will either enable to change the value of another digit
	//        // or if all digits have been changed, to apply the setting
	//        if (button == 0) {
	//          //button = 1;
	//          if (digitPos < 7)
	//            digitPos++;
	//          else {
	//            digitPos = 0;
	//            menuState = 0;
	//            sigGen.setFreq(frequency);
	//          }
	//        } else if (button == 2) {
	//          //button = 1;
	//          digitPos = 0;
	//          menuState = 0;
	//        }
	//        // Set the blinking cursor on the digit you can currently modify
	//        //lcd.setCursor(9 - digitPos, 0);
	//      } break;
	//
	//    // Phase setting
	//    case 4: {
	//        if (button == 0) {
	//          //button = 1;
	//          if (digitPos < 3)
	//            digitPos++;
	//          else {
	//            digitPos = 0;
	//            menuState = 0;
	//            sigGen.setPhase(phase);
	//          }
	//        }
	//        //lcd.setCursor(5 - digitPos, 1);
	//      } break;
	//    // Change the mode (sine/triangle/clock)
	//    case 5: {
	//        if (button == 0) {
	//          //button = 1;
	//          menuState = 0;
	//          sigGen.mode(selectedWaveform);
	//        }
	//        //lcd.setCursor(13 ,1);
	//      } break;
	//    // Just in case we messed something up
	//    default: {
	//        menuState = 0;
	//      }
	//  }

}

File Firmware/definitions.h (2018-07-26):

// definitions.h
#define DEBUG


const PROGMEM String __FIRMWARE_VERSION__ = "0.1pre-alpha" ;

//Uncomment the line below if you want to change the Phase instead of the FREQ register
//#define usePhase

const uint8_t rotaryEncoderPinBtn = 1;
const uint8_t rotaryEncoderPinA = 3;
const uint8_t rotaryEncoderPinB = 2;
int16_t rotaryEncoderLastPos = 0;
int16_t rotaryEncoderPos = 0;
bool isAccelerated = false;

class Direction {
public:
	enum dir {
		NONE,
		CW, //Clockwise
		CCW, //Counterclockwise
	};
};

class Menu {
public:
	enum Menu_e {
		NullItem,
		FreqSet,
		Mode,
		Power,
		Phase,
		Sweep,
		Settings,
		Help,
		lastItem
	};
};
const PROGMEM String MenuLabel[] = {
	"",
	"FREQUENCY",
	"WAVEFORM",
	"OUTPUT",
	"PHASE",
	"SWEEP",
	"SETTINGS",
	"HELP"
};

const uint8_t AD9833_FsyncPin = 10;
const uint32_t AD9833_ClkFreq = 24000000;

const uint8_t TFT_CS = 9;
const uint8_t TFT_DC = 8;

// Variables used to input data and walk through menu
Menu::Menu_e menuSelected = Menu::NullItem; //highligted menu item selected with rotary encoder
Menu::Menu_e menuActive = Menu::NullItem; //currently active menu item
bool buttonIsHeld = false;  //check if button is still held or is a new hold event after a release event
uint8_t digitPos = 0;  //highlighted digit in frequency set menu, 0-4 for digits, 5 for frequency unit
uint8_t numDigits;
const uint32_t maxFrequency = AD9833_ClkFreq / 2; //12000000 half the frequency of the Clock
const uint16_t maxPhase = 4095; // Only used if you enable PHASE setting instead of FREQ register
uint32_t newFrequency[5]; //stores digits of actual frequency for digit by digit modification in frequency set menu
uint8_t newFrequencyExp = 0; // 


uint8_t freqRegister = 0; // Default FREQ register is 0

const PROGMEM String waveformLabel[] = { "SINE", "TRINGLE", "SQUARE" };
// Variables used to store phase, frequency, mode and power
uint8_t selectedWaveform = 0; //0 = Sine, 1 = Triangle, 2 = Square
uint32_t frequency = 1000;
unsigned long phase = 0; // Only used if you enable PHASE setting instead of FREQ register
bool currentPowerState = false;



//some colors based on https://xkcd.com/color/rgb/ 
#define ROSEPINK 0xFCB3
#define APPLEGREEN 0x5725
#define LIGHTBLUE 0x07FF
#define PALEVIOLET 0xBD5F
#define AQUA 0x1759
#define CERULEAN 0x03F8
#define HOTMAGENTA 0xE078
#define SAPPHIRE 0x3995
#define MINTYGREEN 0x176E
#define TOPAZ 0x3618
#define MUDBROWN 0x6A64
#define PISSYELLOW 0xEF00
#define DULLORANGE 0xCC69
#define MEDIUMGREY 0x83EE

// Color definitions
#define BLACK    0x0000
#define BLUE     0x001F
#define RED      0xF800
#define GREEN    0x07E0
#define CYAN     0x07FF
#define MAGENTA  0xF81F
#define YELLOW   0xFFE0 
#define WHITE    0xFFFF
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

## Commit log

2018-06-27 Revision 1
    Fertige Platinen für Platinenfräse geeignet.
    Todo: Bauteile Bezeichnungen auf Silkscreen richtig positionieren
    [Funktionsgenerator Controller.brd, Funktionsgenerator Controller.sch, Funktionsgenerator Power Supply.brd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]
2018-06-28 Added BOM
2018-07-02 Moved Files to subfolder
    [Funktionsgenerator Controller.brd, Funktionsgenerator Controller.sch, Funktionsgenerator Power Supply.brd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]
2018-07-10 Added Resistor to limit current for TFT Backlight
    Das TFT Display wurde zu heiß, da der Vorwiderstand für die Hintergrundbeleuchtung des TFT lediglich 6Ohm beträgt. Durch einen weiteren Vorwiderstand von 22Ohm konnte die Wärmeentwicklung des Display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
    [Funktionsgenerator Controller.brd, Funktionsgenerator Controller.sch]
2018-07-10 Changes to Bootup Scrreen, some fixes
    [FuncGen.ino, definitions.h]
2018-07-10 Added Vector file for MDF/Acrylic Case
2018-07-11 Rotary Encoder zu Liste hinzugefügt
2018-07-12 added Encoder Library
2018-07-12 VCC on encoder connector for external pull-up
    [Funktionsgenerator Controller.brd, Funktionsgenerator Controller.sch]
2018-07-15 added mainscreen showing frequency, hold button for power on/off
2018-07-16 moved labels on, added net names
    [Funktionsgenerator Controller.brd, Funktionsgenerator Controller.sch]
2018-07-18 fixed overflow bug in frequency change function
    [FuncGen.ino]
2018-09-27 Added trimmer for offset adjustment and some fixes
    [Funktionsgenerator Controller.brd, Funktionsgenerator Controller.sch]

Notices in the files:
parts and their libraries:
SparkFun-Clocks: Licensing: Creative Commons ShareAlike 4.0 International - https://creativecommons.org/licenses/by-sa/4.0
